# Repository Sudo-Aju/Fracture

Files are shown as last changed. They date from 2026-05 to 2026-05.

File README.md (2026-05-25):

<div align="center">

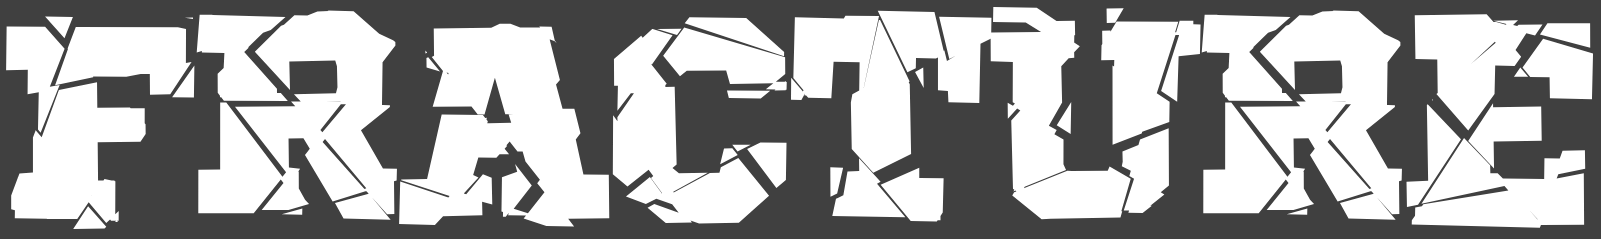
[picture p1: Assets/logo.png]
FractureLogo
# 

A Bluetooth Powered 48-Key Split Keyboard

<p>




</p>

### _A keyboard designed to physically split apart - because productivity and aesthetics shouldn't stay connected._

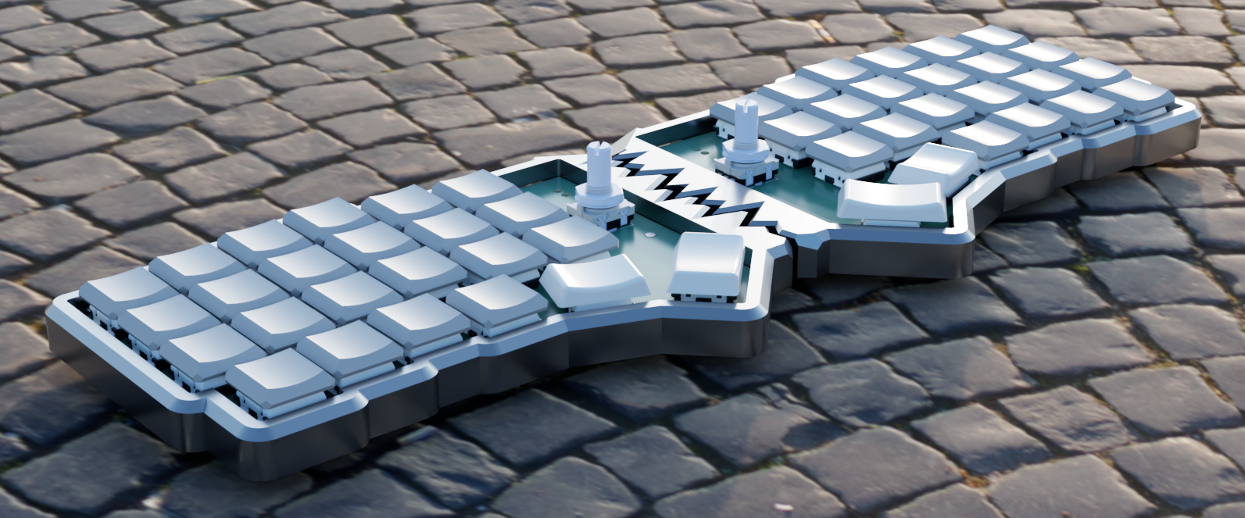
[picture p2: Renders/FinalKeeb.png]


</div>

---

# Overview

**Fracture** is a wireless 48-key split mechanical keyboard built around modularity, portability, and aesthetics.

Unlike traditional keyboards, Fracture is designed to **literally seperate into two halves**, giving users a more ergonomic typing expereience while creating a visually unique "fractured" appearance.

Built using the **Seed Studio XIAO nRF52840**, Kailh Choc Switches, and low-profile keycaps, Fracture blends minimalism with functionaly in a compact wireless setup.

---

# Gallery

<div align="center">

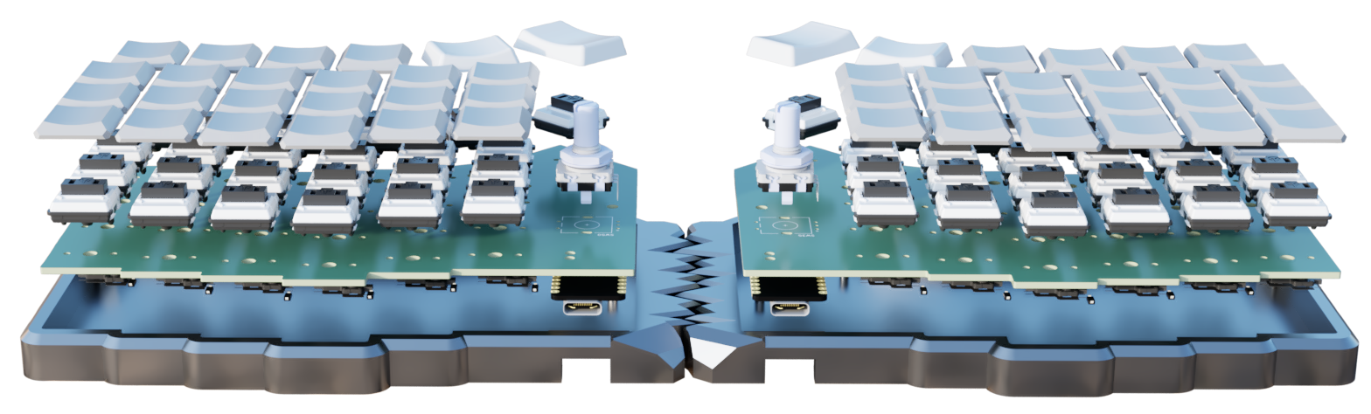
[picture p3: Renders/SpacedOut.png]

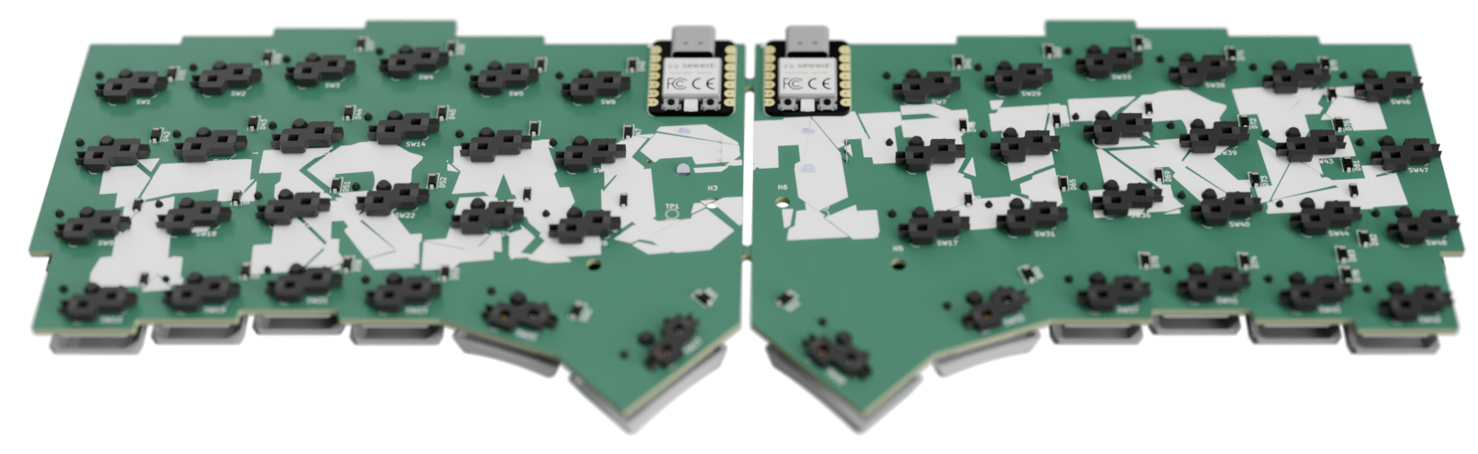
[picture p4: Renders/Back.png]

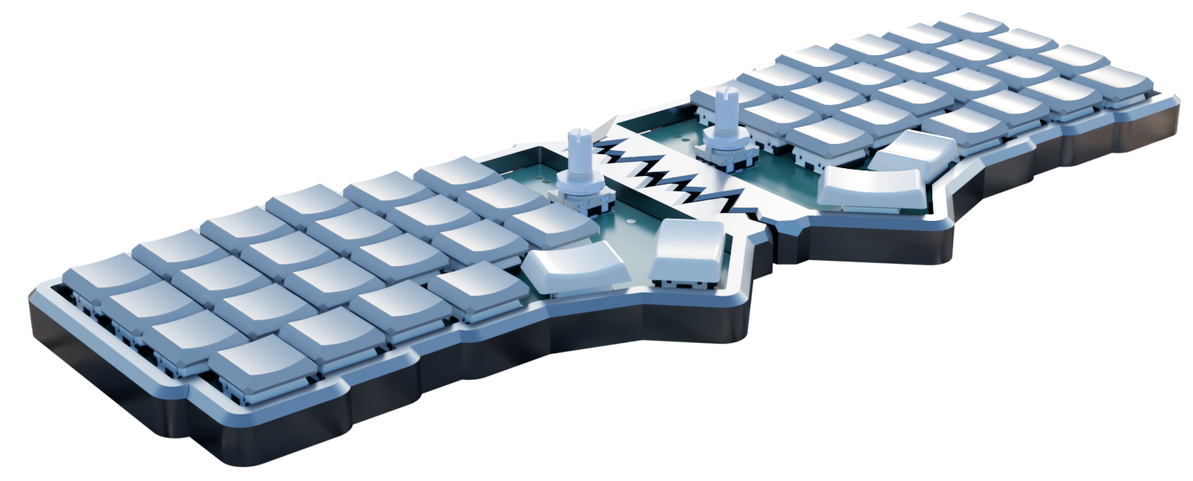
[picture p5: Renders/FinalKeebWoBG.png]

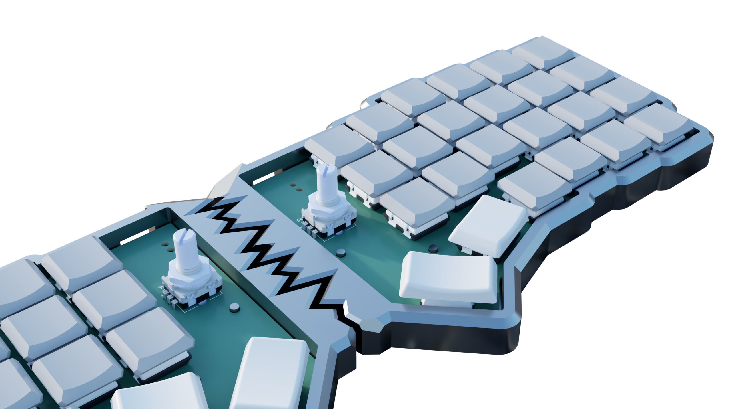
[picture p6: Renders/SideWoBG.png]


</div>

---

# Zine

<div align="center">

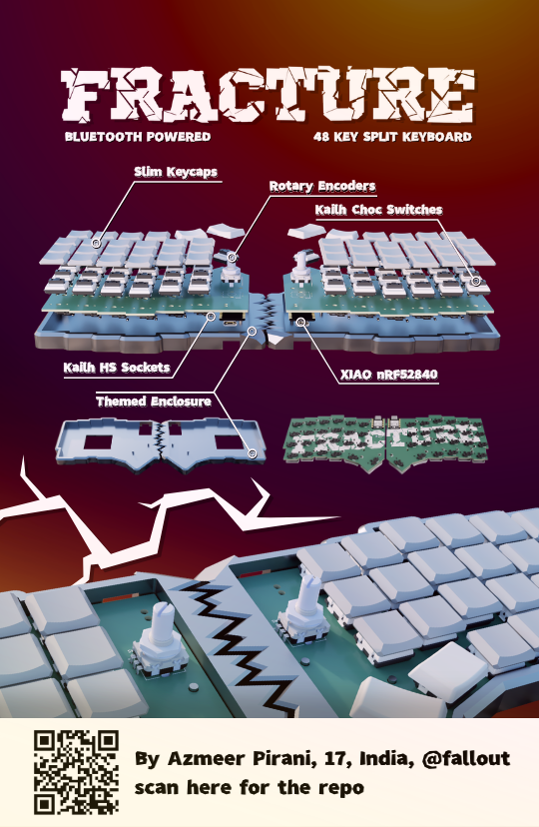
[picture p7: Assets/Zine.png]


</div>

---

# Motivation

Most keyboards are designed around a fixed layout.

Fracture was built around a different idea:

> _What if keyboard itself reflected flexibility?_

The split design is inspired from Corne keyboards:
- Better ergonomics
- Adjustable positioning
- Cleaner desk setups
- Compact portability
- A visually striking design language

The project also explores how industrial design and hardware aesthetics can coexist with practicality.

---

# Assembly Guide

## Hardware

### 1. Order the PCB

Navigate to:

```bash
PCB/Production/
```

Upload the included Gerber files to your preferred PCB manufacturer and order the PCB.

### 2. Order the Components
All required components and purchase links are available inside: (India)
```bash
PCB/BOM/BOM.csv
```
Order all listed parts before starting assembly
### 3. Solder the SMD Components

Start by soldering first few SMD components on the PCB:
- Diodes are on the front
- MCU pads are on the back

It is recommended to use:
- Flux
- Dine-tip soldering iron
- Tweezers

### 4. Install Hot-Swap Sockets
- Solder all Kailh hot-swap sockets onto the PCB carefully.

- Ensure every socket sits completely flat agains the PCB before soldering.

### 5. Install the Rotary Encoders

- Solder the EC11 rotary encoders in their designated positions.

- Make sure they are aligned staright before fully soldering.

### 6. Insert the MCU

- Now the XIAO nRF52840 (or any other if changed) controllers onto the PCB. 

### 7. Assemble the Case

- Print the 3D enclosure, and inert the PCB by aligning its M3 screw holes with the joints.

### 8. Install Switches

- Insert all Kailh Choc switches into the plate and hot-swap sockets.

- Check alignment carefully to avoid bent pins.

### 9. Install Keycaps

- Press the keycaps firmly onto the switches,

## Firmware Installation

### 1. Enter Bootloader Mode
While the keyboard is unplugged:

- Short the `BOOT` and `GND` pads using tweezers or screwdriver
- Plug in the USB cable

or

- Double press the reset button on the XIAO nRF52840

A new drive should appear on your computer

### 2. Download Firmware

Naviagte to:
```bash
Firmware/
```
and download `adafruit-circuitpython-Seeed_XIAO_nRF52840_Sense-en_US-10.2.1.uf2` or compile the files in `Firmware/Config` file if ZMK is to be used.

### 3. Flash the Firmware

Drag and drop the `uf2` file onto the mounted drive.
Repeat for the second half as well.

---

# BOM

|Designator |Function |Value |Footprint |Quantity|Price (INR)|Price (USD)|Amount |Link |
|---|---|---|---|---|---|---|---|---|
|PCB |Main PCB | | |1 |₹3,969.00  |$40.71 |$40.71 |https://www.pcbpower.com/page/PCBDetails/UXVvdGF0aW9ucw==/SU5RNjAzNTY0/ |
|Keycaps u1 1 |Slim Keycaps |Chocfox CFX Choc Blank Keycaps u1 |SW_choc_v1_HS_CPG135001S30_1u |40 |₹35.00 |$0.36 |$14.36 |https://neomacro.in/products/chocfox-cfx-choc-blank-keycaps |
|Keycaps u1 2 |Slim Keycaps |Chocfox CFX Choc Blank Keycaps u1 |SW_choc_v1_HS_CPG135001S30_1u |4 |₹35.00 |$0.36 |$1.44  |https://neomacro.in/products/chocfox-cfx-choc-blank-keycaps?variant=48049351590166 |
|Keycaps u1.25 |Slim Keycaps |Chocfox CFX Choc Blank Keycaps u1.25|SW_choc_v1_HS_CPG135001S30_1.25u |2 |₹55.00 |$0.56 |$1.13  |https://neomacro.in/products/chocfox-cfx-choc-blank-keycaps?variant=48049351622934 |
|Keycaps u1.5 |Slim Keycaps |Chocfox CFX Choc Blank Keycaps u1.5 |SW_choc_v1_HS_CPG135001S30_1.5u |2 |₹55.00 |$0.56 |$1.13  |https://neomacro.in/products/chocfox-cfx-choc-blank-keycaps?variant=48049351655702 |
|Enclosure |Print Legion | | |1 |₹400.00 |$4.10 |$4.10  |https://printlegion.hackclub.com/ |
|D35, D36, D37, D38, D39, D40, D41, D42, D43, D44, D45, D46, D47, D48, D49, D50, D51, D52, D53, D54, D55, D56, D57, D58, D59, D60, D61, D62, D63, D64, D65, D66, D67, D68, D69, D70, D71, D72, D73, D74, D75, D76, D77, D78, D80, D81, D82, D83 |Diodes |1N4148W |D_SOD-123 |48 |₹0.70 |$0.01 |$0.34  |https://robu.in/product/1n4148w-sod-123-1206-diodereel-of-3000/ |
|SW1, SW2, SW3, SW4, SW5, SW6, SW7, SW8, SW9, SW10, SW11, SW12, SW13, SW14, SW15, SW16, SW17, SW18, SW19, SW20, SW21, SW22, SW23, SW24, SW26, SW29, SW30, SW31, SW33, SW34, SW36, SW37, SW38, SW39, SW40, SW41, SW42, SW43, SW44, SW45, SW46, SW47, SW48, SW49, SW25, SW32, SW27, SW28|Keys |Kailh Choc u1 |SW_choc_v1_HS_CPG135001S30 |44 |₹54.55 |$0.56 |$24.62 |https://neomacro.in/products/kailh-choc-v1-switches |
|SW35, SW50 |Rotary Encoders |EC11 |RotaryEncoder_Alps_EC11E_Vertical_H20mm|2 |₹42.00 |$0.43 |$0.86  |https://www.flyrobo.in/ec11-rotary-encoder-half-shaft-handle-potentiometer-15mm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|
|U1, U2 |MCU |XIAO nRF52840 |modified-XIAO-nRF52840-SMD |2 |₹1,152.00  |$11.82 |$23.63 |https://robu.in/product/seeed-studio-xiao-ble-nrf52840/ |
|SW1, SW2, SW3, SW4, SW5, SW6, SW7, SW8, SW9, SW10, SW11, SW12, SW13, SW14, SW15, SW16, SW17, SW18, SW19, SW20, SW21, SW22, SW23, SW24, SW26, SW29, SW30, SW31, SW33, SW34, SW36, SW37, SW38, SW39, SW40, SW41, SW42, SW43, SW44, SW45, SW46, SW47, SW48, SW49 |Hot-swap Sockets|Kailh HS choc v1 |SW_choc_v1_HS_CPG135001S30 |48 |₹14.00 |$0.14 |$6.89  |https://neomacro.in/products/kailh-choc-pg1350-hot-swap-sockets?variant=48049369907478 |
|TOTAL | | | | | | |$119.21| |
---

# Features

- **Physically Splits Into Two Halves**
- **Bluetooth Powered**
- **48-Key Layout**
- **Rotary Encoders**
- **Low Profile Kailh Choc Switches**
- **Kailh Hot-Swap Sockets**
- **Powered by XIAO nRF52840**
- **Custom Themed Enclosure**
- **Slim Keycaps**
- **Portable & Lightweigth**
- **Fully Custom PCB**

___

# Hardware Stack

| Component | Description |
|---|---|
| MCU | Seeed Studio XIAO nRF52840 |
| Switches | Kailh Choc Low Profile |
| Sockets | Kailh Hot Swap Sockets |
| Layout | 48-key Split |
| Connectivity | Bluetooth |
| Encoders | Rotary Encoders (360 Degree Rotary Encoder EC16)
| Keycaps | Slim Low-Profile Keycaps |
| PCB | Custom Designes |
| Case | Themed Fracture Enclosure |

---

# PCB Design

The PCB was custom designed specifically for the Fracture layout and enclosure.

Features include:
- Wireless microcontroller support
- Rotary encoder integration
- Kailh hot-swap compatibility
- Compact routing for slip profile construction

## PCB
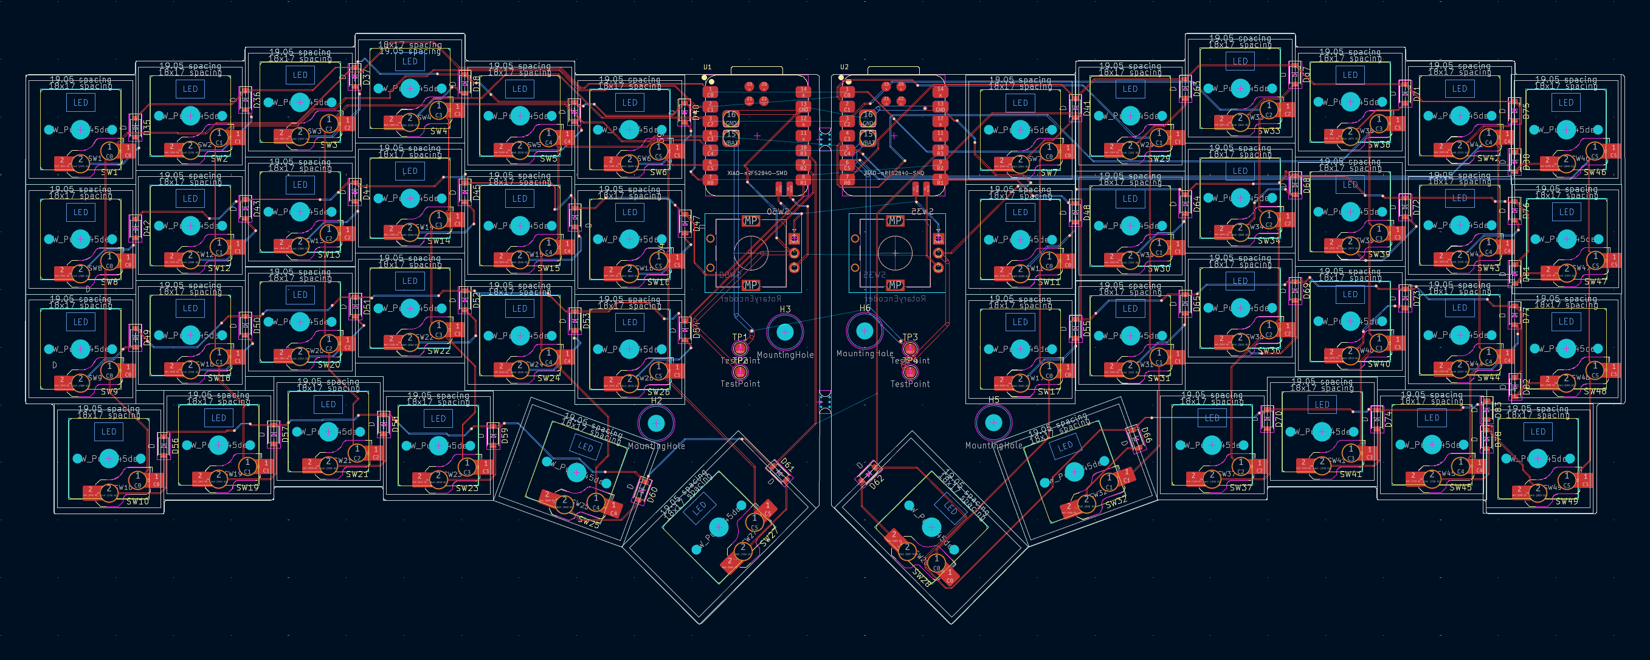
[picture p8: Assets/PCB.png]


## Schematic
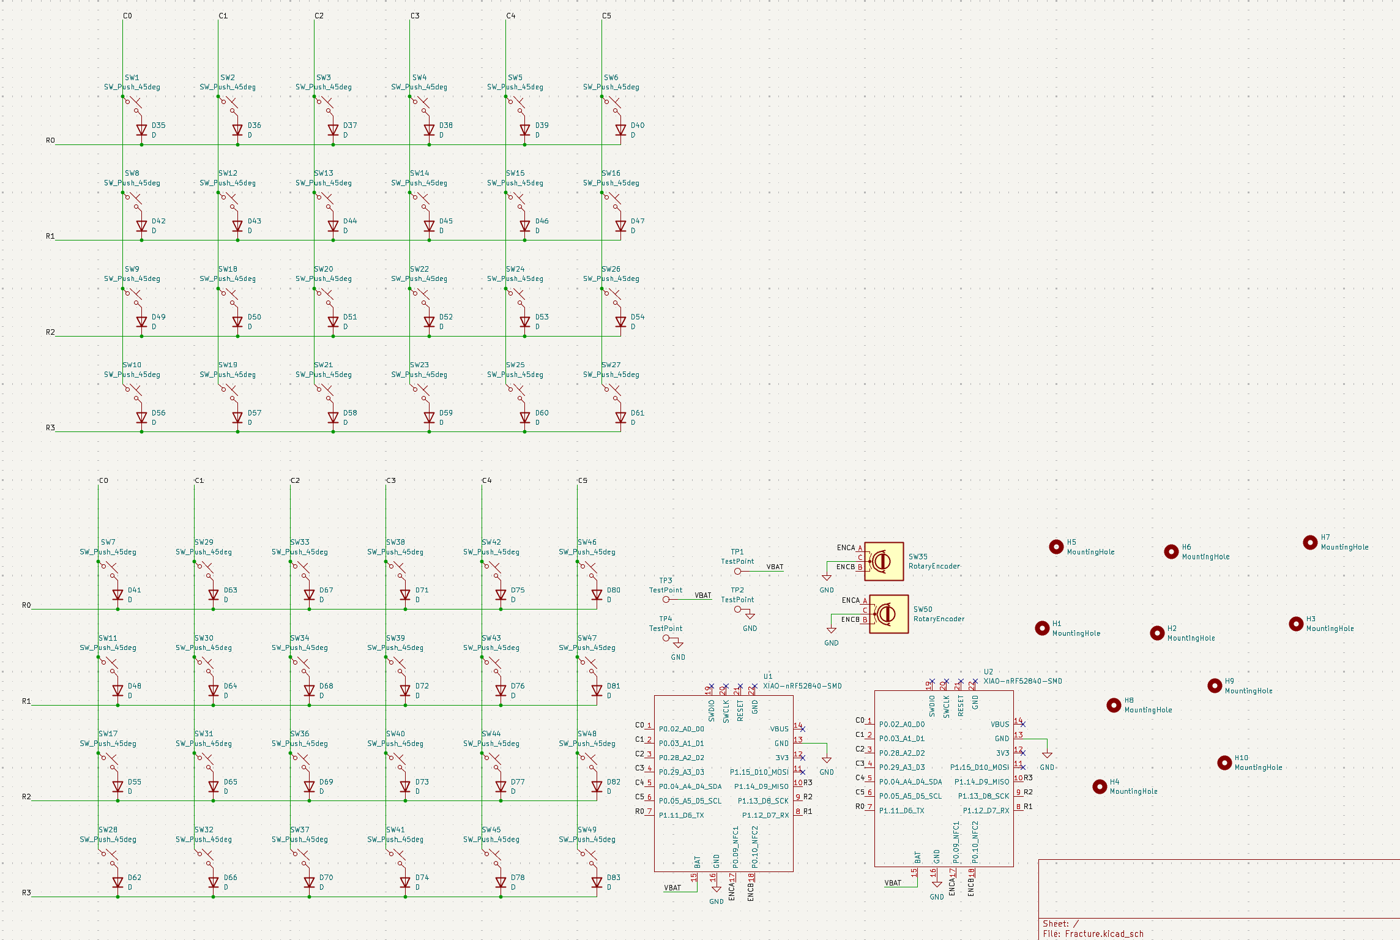
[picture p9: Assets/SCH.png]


## Placement
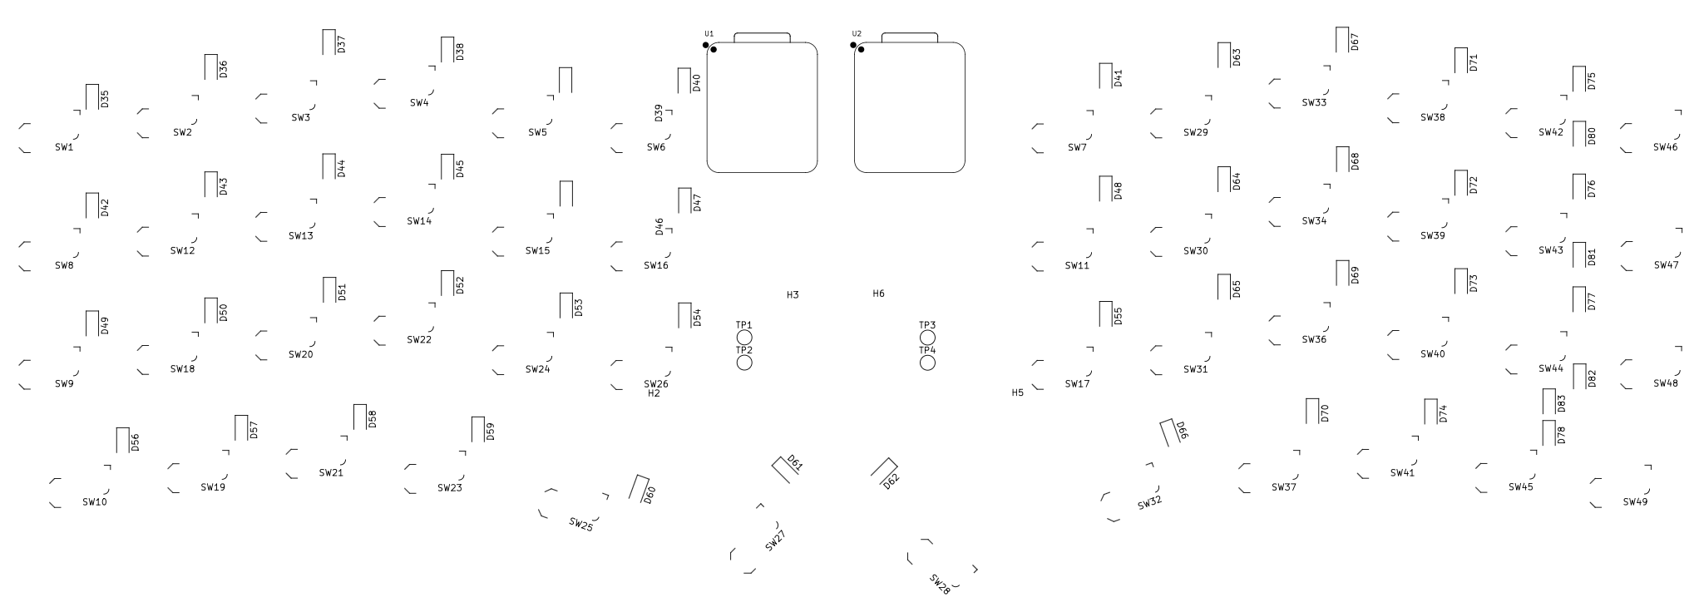
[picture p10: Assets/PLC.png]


---

# Enclosure

The enclosure follows the central "fracture" design language:
- Broken center seam
- Aggresive angular styling
- Compact low-profile body
- Seamless split mechanism

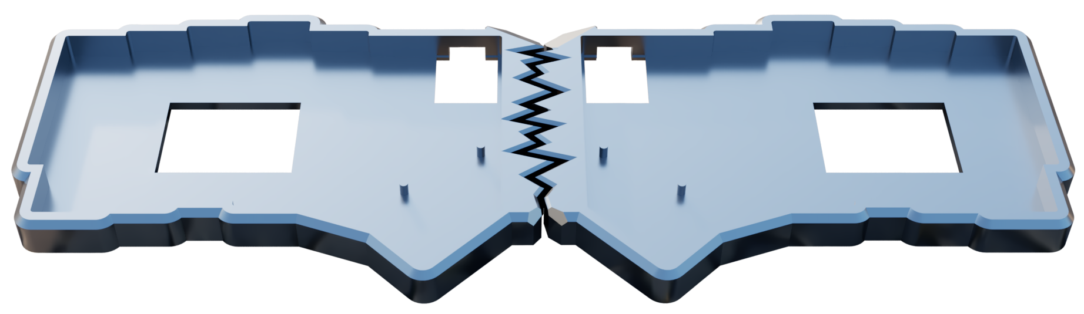
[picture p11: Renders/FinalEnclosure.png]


The goal was to make the keyboard feel more like a designed object rather than just a perpheral.

---

# Firmware (ZMK)

Firmware features:
- Bluetooth support
- Custom keymaps
- Layer switching
- Encoder controls

---

```bash
Fracture/
├── PCB/
├── CAD/
├── Firmware/
├── Assets/
└── README.md
```

---

# Current Status

- [X] Inital Concept
- [X] Layout Finalized
- [X] Enclosure Prototype
- [X] PCB design
- [X] Firmware
- [ ] Final Build
- [ ] Firmware Optimization

---

# Contributing 

Contributions, suggestions, and feedback are welcome.

If you'd like to improve Fracture:
1. Fork or Clone the repository 
```bash
git clone https://github.com/Sudo-Aju/Fracture.git
cd Fracture
```
2. Create your feature branch (if forked)
3. Commit your changes
4. Open a pull request

---

# Creator

### Azmeer Pirani
17 • India • @fallout

Built with a love for:
- hardware design
- industrial aesthetics
- mechanical keyboards
- expirimental products

---

# License

This project is licensed under the MIT License.

---

<div align="center">

## FRACTURE

### _Break the keyboard. Not the workflow._

</div>

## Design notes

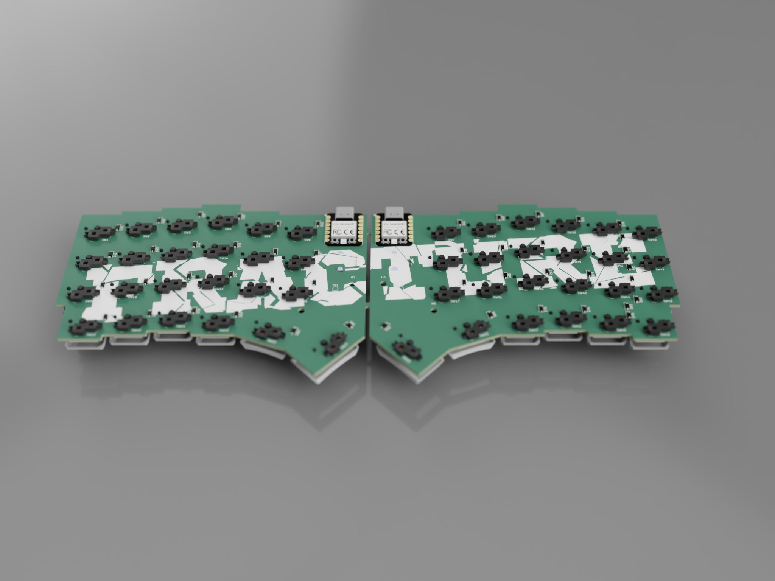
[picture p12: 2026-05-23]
Renders/render1.png

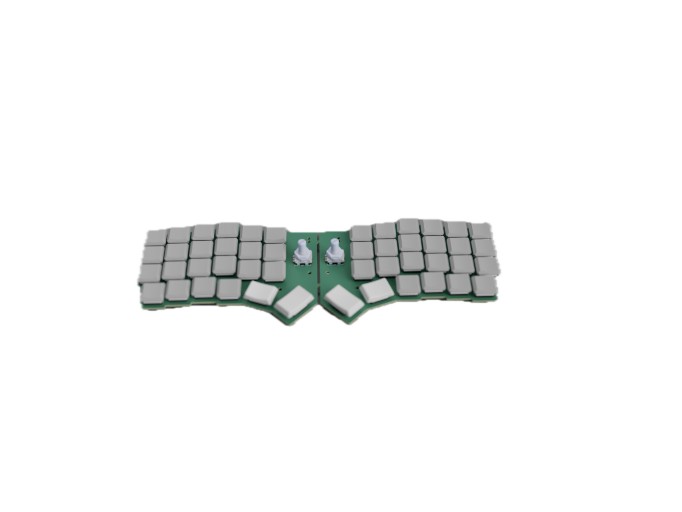
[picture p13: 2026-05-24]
Renders/render2.png

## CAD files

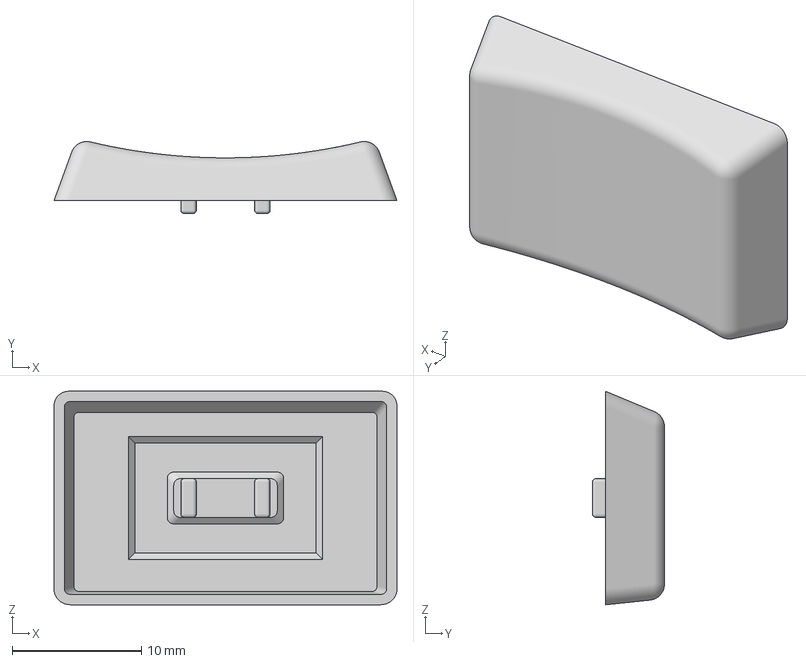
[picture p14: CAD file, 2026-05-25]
CAD/Components/Kailh Slim Keycap u1.5.3mf
26.5 x 5.56 x 16.5 mm

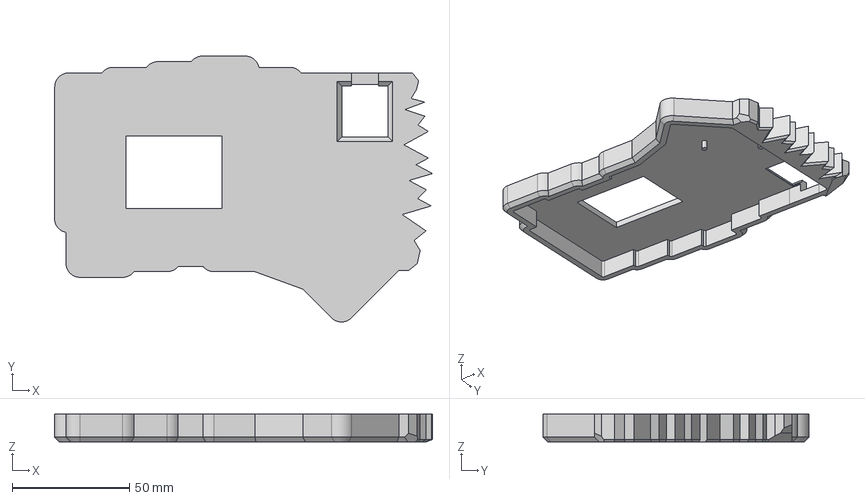
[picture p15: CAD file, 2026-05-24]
CAD/Left.step
161.4 x 113.6 x 11.8 mm

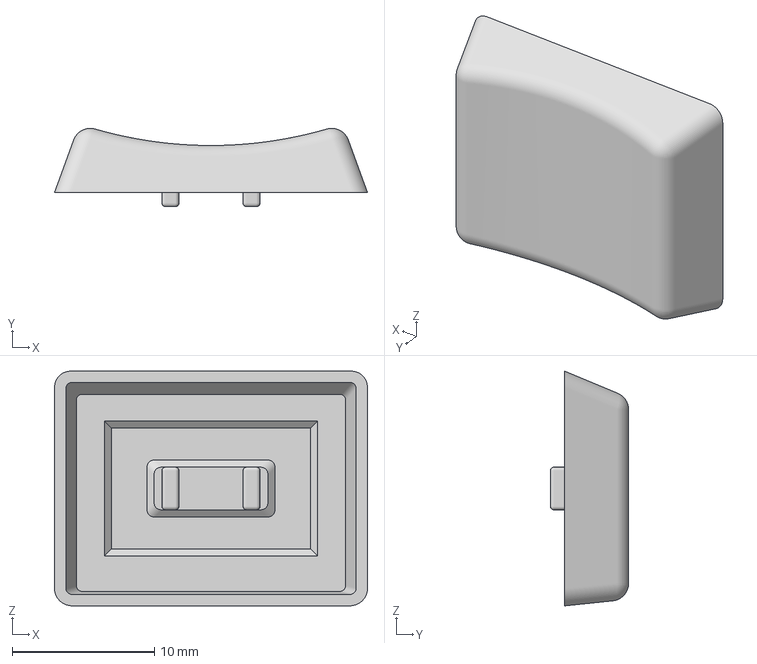
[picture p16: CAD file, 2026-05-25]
CAD/Components/Kailh Slim Keycap u1.25.3mf
22.0 x 5.50 x 16.5 mm

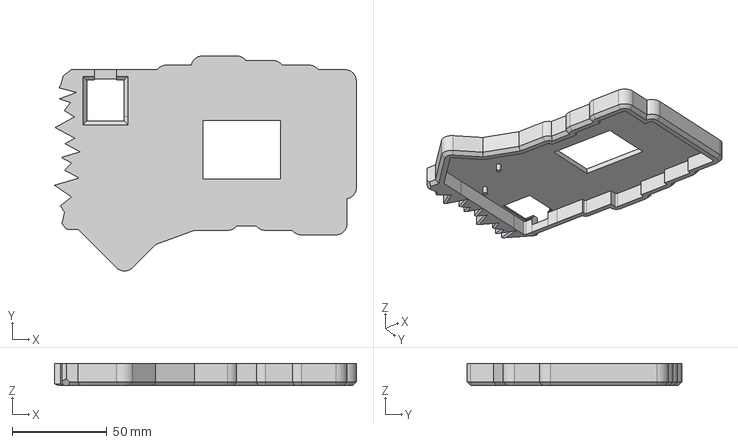
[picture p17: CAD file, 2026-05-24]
CAD/Right.step
159.5 x 113.6 x 11.8 mm

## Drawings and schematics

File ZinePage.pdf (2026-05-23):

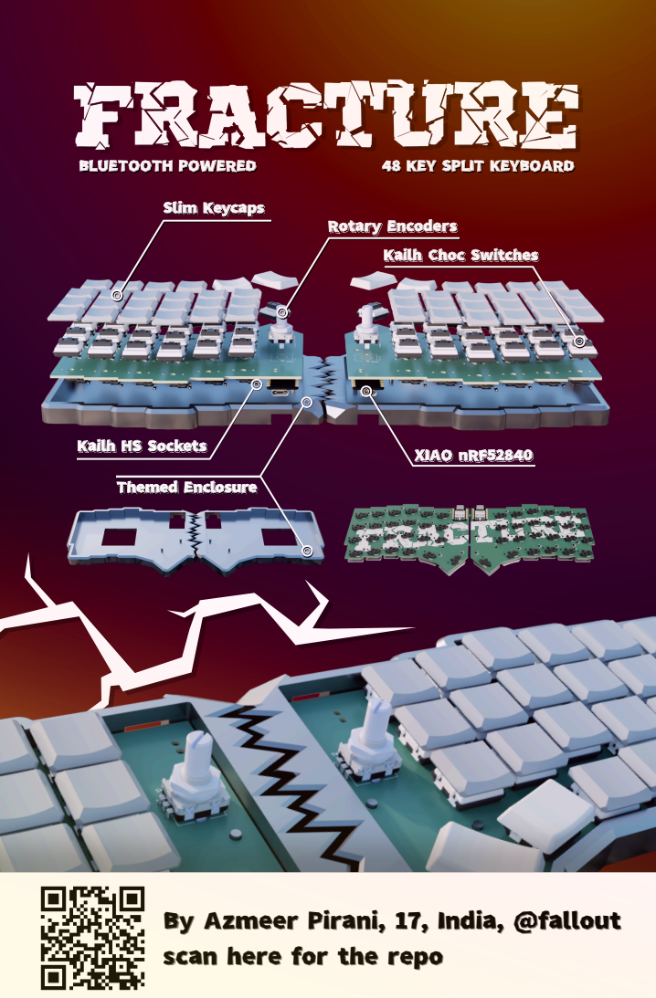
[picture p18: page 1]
SSlliimm KKeeyyccaappss; TThheemmeedd EEnncclloossuurree; XXIIAAOO nnRRFF5522884400; KKaaiillhh; HHSS SSoocckkeettss; BBBLLLUUUEEETTTOOOOOOTTTHHH PPPOOOWWWEEERRREEEDDD; 444888 KKKEEEYYY SSSPPPLLLIIITTT KKKEEEYYYBBBOOOAAARRRDDD

Rotary Encoders
Kailh Choc Switches

By Azmeer Pirani, 17, India, @fallout
scan here for the repo

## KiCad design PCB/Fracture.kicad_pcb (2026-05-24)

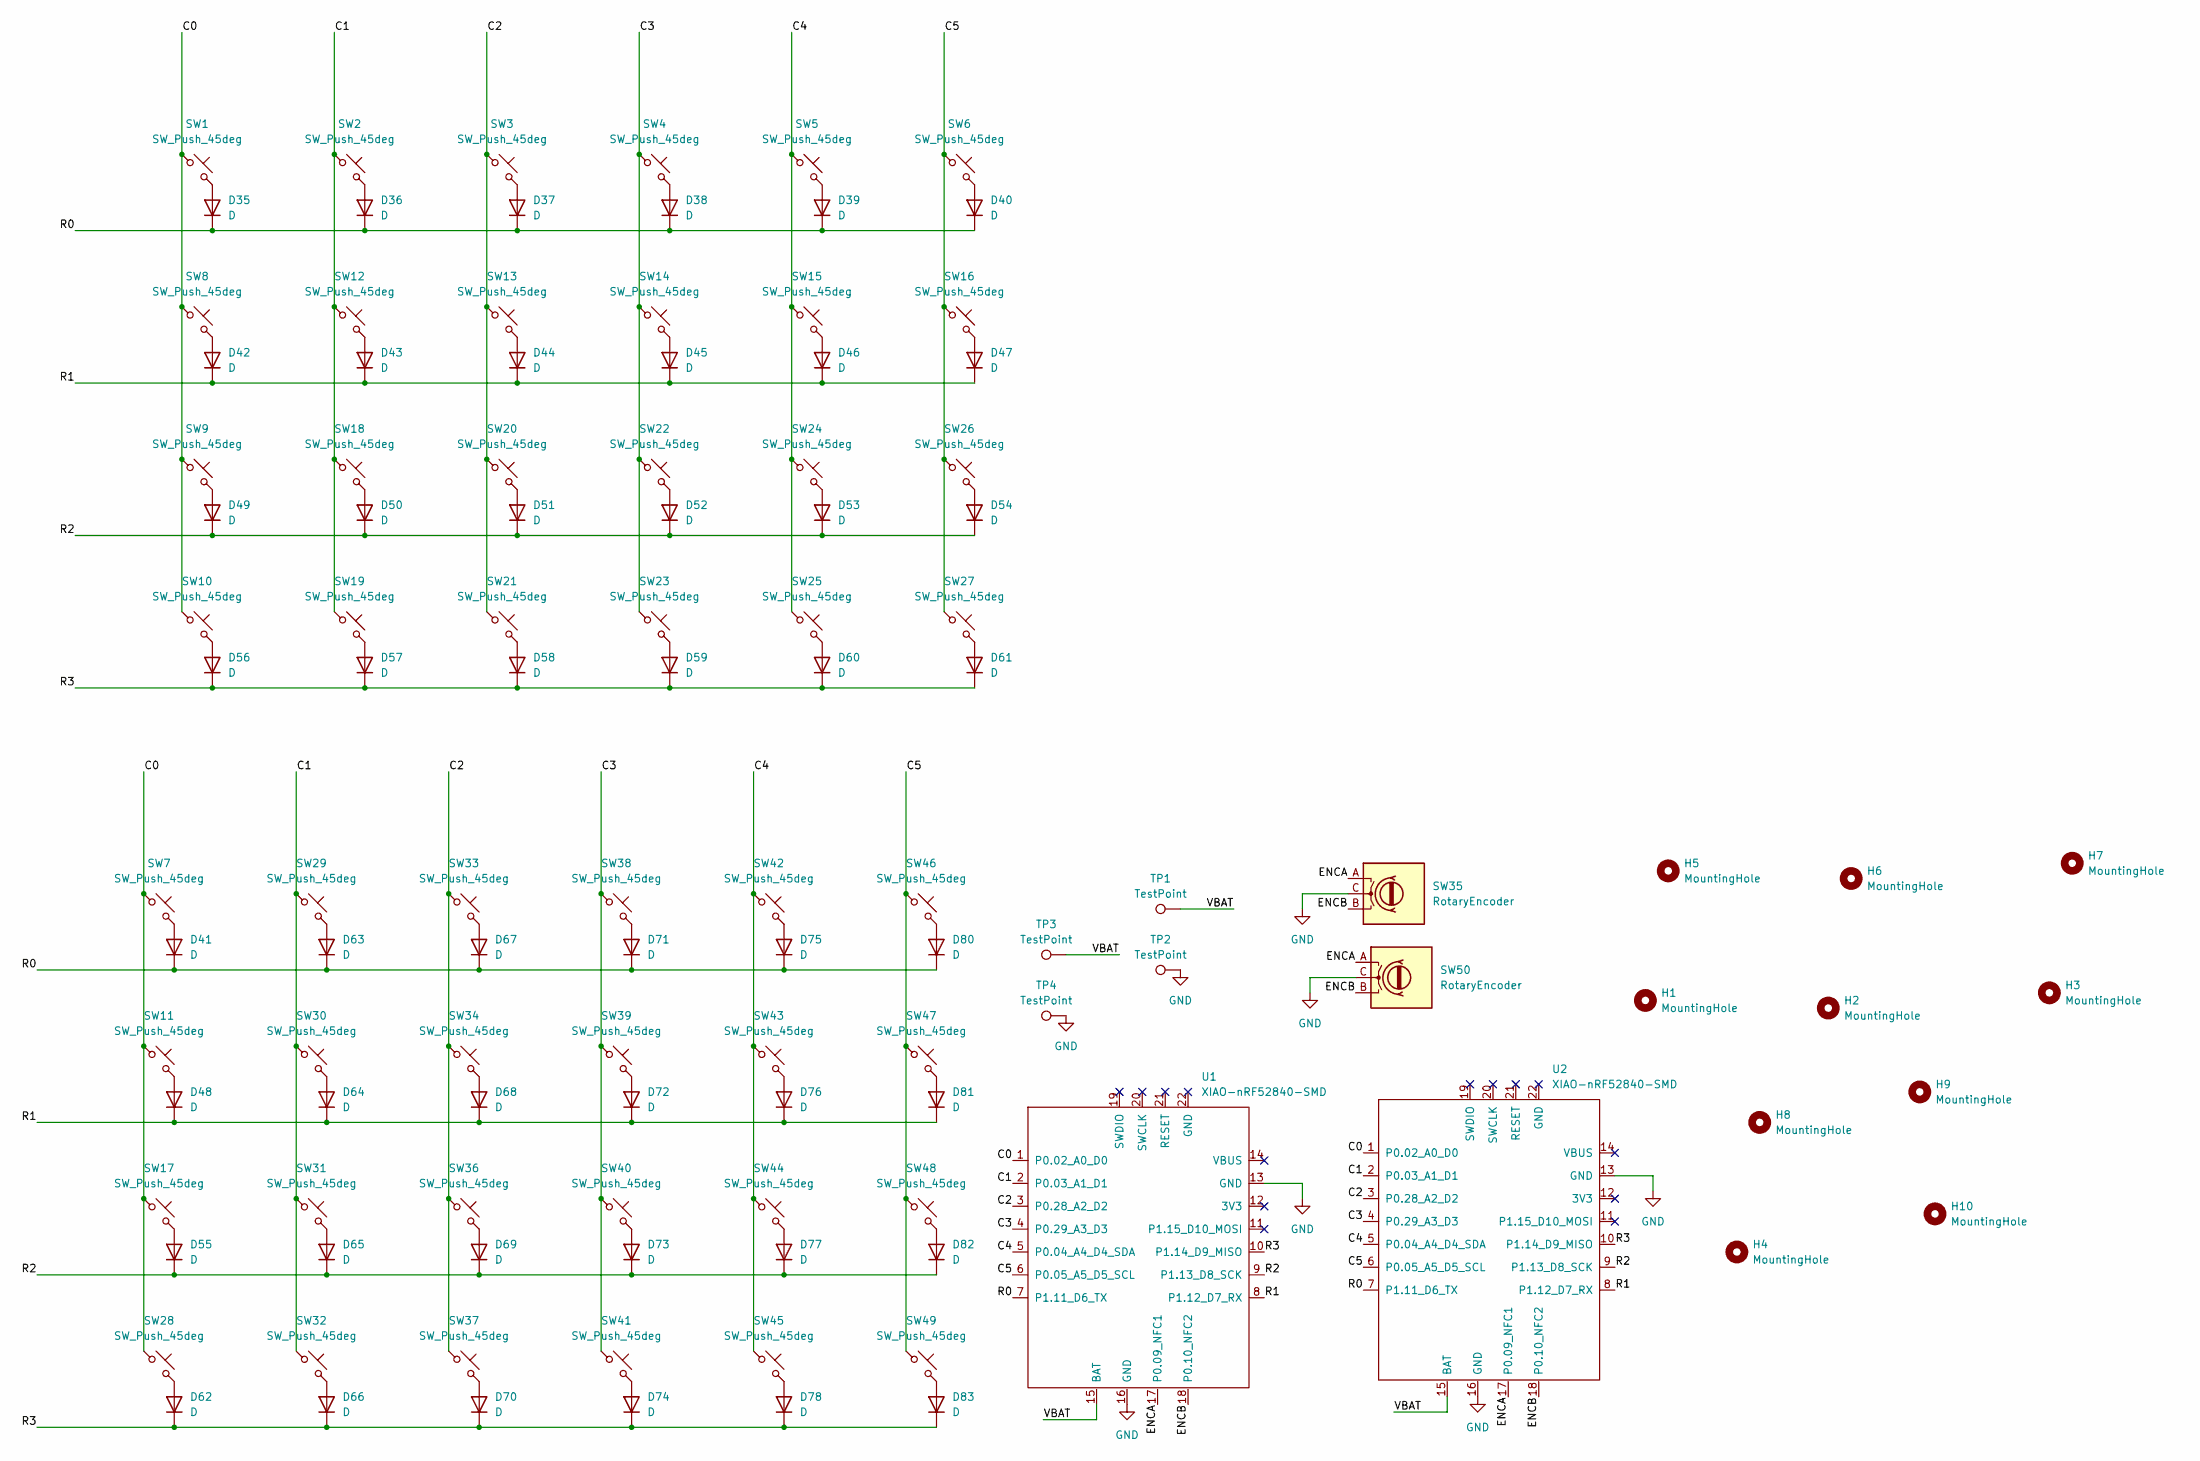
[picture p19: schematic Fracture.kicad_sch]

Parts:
D35, D36, D37, D38, D39, D40, D41, D42, D43, D44, D45, D46, D47, D48, D49, D50, D51, D52, D53, D54, D55, D56, D57, D58, D59, D60, D61, D62, D63, D64, D65, D66, D67, D68, D69, D70, D71, D72, D73, D74, D75, D76, D77, D78, D80, D81, D82, D83: D; D_SOD-123
H1, H2, H3, H4, H5, H6, H7, H8: MountingHole; MountingHole_3mm
H9, H10: MountingHole; MouseBite-Slot_2.0x2.0mm_outset_D0.5mm_P0.85mm_3h
SW1, SW2, SW3, SW4, SW5, SW6, SW7, SW8, SW9, SW10, SW11, SW12, SW13, SW14, SW15, SW16, SW17, SW18, SW19, SW20, SW21, SW22, SW23, SW24, SW25, SW26, SW27, SW28, SW29, SW30, SW31, SW32, SW33, SW34, SW36, SW37, SW38, SW39, SW40, SW41, SW42, SW43, SW44, SW45, SW46, SW47, SW48, SW49: SW_Push_45deg; SW_choc_v1_HS_CPG135001S30_1u
SW35, SW50: RotaryEncoder; RotaryEncoder_Alps_EC11E_Vertical_H20mm
TP1, TP2, TP3, TP4: TestPoint; TestPoint_Pad_D2.0mm
U1, U2: XIAO-nRF52840-SMD; modified-XIAO-nRF52840-SMD

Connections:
/C0: SW1.1, SW7.1, SW8.1, SW9.1, SW10.1, SW11.1, SW17.1, SW28.1, U1.1 (P0.02_A0_D0), U2.1 (P0.02_A0_D0)
/C1: SW2.1, SW12.1, SW18.1, SW19.1, SW29.1, SW30.1, SW31.1, SW32.1, U1.2 (P0.03_A1_D1), U2.2 (P0.03_A1_D1)
/C2: SW3.1, SW13.1, SW20.1, SW21.1, SW33.1, SW34.1, SW36.1, SW37.1, U1.3 (P0.28_A2_D2), U2.3 (P0.28_A2_D2)
/C3: SW4.1, SW14.1, SW22.1, SW23.1, SW38.1, SW39.1, SW40.1, SW41.1, U1.4 (P0.29_A3_D3), U2.4 (P0.29_A3_D3)
/C4: SW5.1, SW15.1, SW24.1, SW25.1, SW42.1, SW43.1, SW44.1, SW45.1, U1.5 (P0.04_A4_D4_SDA), U2.5 (P0.04_A4_D4_SDA)
/C5: SW6.1, SW16.1, SW26.1, SW27.1, SW46.1, SW47.1, SW48.1, SW49.1, U1.6 (P0.05_A5_D5_SCL), U2.6 (P0.05_A5_D5_SCL)
/ENCA: SW35.A, SW50.A, U1.17 (P0.09_NFC1), U2.17 (P0.09_NFC1)
/ENCB: SW35.B, SW50.B, U1.18 (P0.10_NFC2), U2.18 (P0.10_NFC2)
/R0: D35.1 (K), D36.1 (K), D37.1 (K), D38.1 (K), D39.1 (K), D40.1 (K), D41.1 (K), D63.1 (K), D67.1 (K), D71.1 (K), D75.1 (K), D80.1 (K), U1.7 (P1.11_D6_TX), U2.7 (P1.11_D6_TX)
/R1: D42.1 (K), D43.1 (K), D44.1 (K), D45.1 (K), D46.1 (K), D47.1 (K), D48.1 (K), D64.1 (K), D68.1 (K), D72.1 (K), D76.1 (K), D81.1 (K), U1.8 (P1.12_D7_RX), U2.8 (P1.12_D7_RX)
/R2: D49.1 (K), D50.1 (K), D51.1 (K), D52.1 (K), D53.1 (K), D54.1 (K), D55.1 (K), D65.1 (K), D69.1 (K), D73.1 (K), D77.1 (K), D82.1 (K), U1.9 (P1.13_D8_SCK), U2.9 (P1.13_D8_SCK)
/R3: D56.1 (K), D57.1 (K), D58.1 (K), D59.1 (K), D60.1 (K), D61.1 (K), D62.1 (K), D66.1 (K), D70.1 (K), D74.1 (K), D78.1 (K), D83.1 (K), U1.10 (P1.14_D9_MISO), U2.10 (P1.14_D9_MISO)
/VBAT: TP1.1 (1_1), TP3.1 (1_1), U1.15 (BAT), U2.15 (BAT)
GND: SW35.C, SW50.C, TP2.1 (1_1), TP4.1 (1_1), U1.13 (GND), U1.16 (GND), U2.13 (GND), U2.16 (GND)
unnamed: D35.2 (A), SW1.2
unnamed: D36.2 (A), SW2.2
unnamed: D37.2 (A), SW3.2
unnamed: D38.2 (A), SW4.2
unnamed: D39.2 (A), SW5.2
unnamed: D40.2 (A), SW6.2
unnamed: D41.2 (A), SW7.2
unnamed: D42.2 (A), SW8.2
unnamed: D43.2 (A), SW12.2
unnamed: D44.2 (A), SW13.2
unnamed: D45.2 (A), SW14.2
unnamed: D46.2 (A), SW15.2
unnamed: D47.2 (A), SW16.2
unnamed: D48.2 (A), SW11.2
unnamed: D49.2 (A), SW9.2
unnamed: D50.2 (A), SW18.2
unnamed: D51.2 (A), SW20.2
unnamed: D52.2 (A), SW22.2
unnamed: D53.2 (A), SW24.2
unnamed: D54.2 (A), SW26.2
unnamed: D55.2 (A), SW17.2
unnamed: D56.2 (A), SW10.2
unnamed: D57.2 (A), SW19.2
unnamed: D58.2 (A), SW21.2
unnamed: D59.2 (A), SW23.2
unnamed: D60.2 (A), SW25.2
unnamed: D61.2 (A), SW27.2
unnamed: D62.2 (A), SW28.2
unnamed: D63.2 (A), SW29.2
unnamed: D64.2 (A), SW30.2
unnamed: D65.2 (A), SW31.2
unnamed: D66.2 (A), SW32.2
unnamed: D67.2 (A), SW33.2
unnamed: D68.2 (A), SW34.2
unnamed: D69.2 (A), SW36.2
unnamed: D70.2 (A), SW37.2
unnamed: D71.2 (A), SW38.2
unnamed: D72.2 (A), SW39.2
unnamed: D73.2 (A), SW40.2
unnamed: D74.2 (A), SW41.2
unnamed: D75.2 (A), SW42.2
unnamed: D76.2 (A), SW43.2
unnamed: D77.2 (A), SW44.2
unnamed: D78.2 (A), SW45.2
unnamed: D80.2 (A), SW46.2
unnamed: D81.2 (A), SW47.2
unnamed: D82.2 (A), SW48.2
unnamed: D83.2 (A), SW49.2

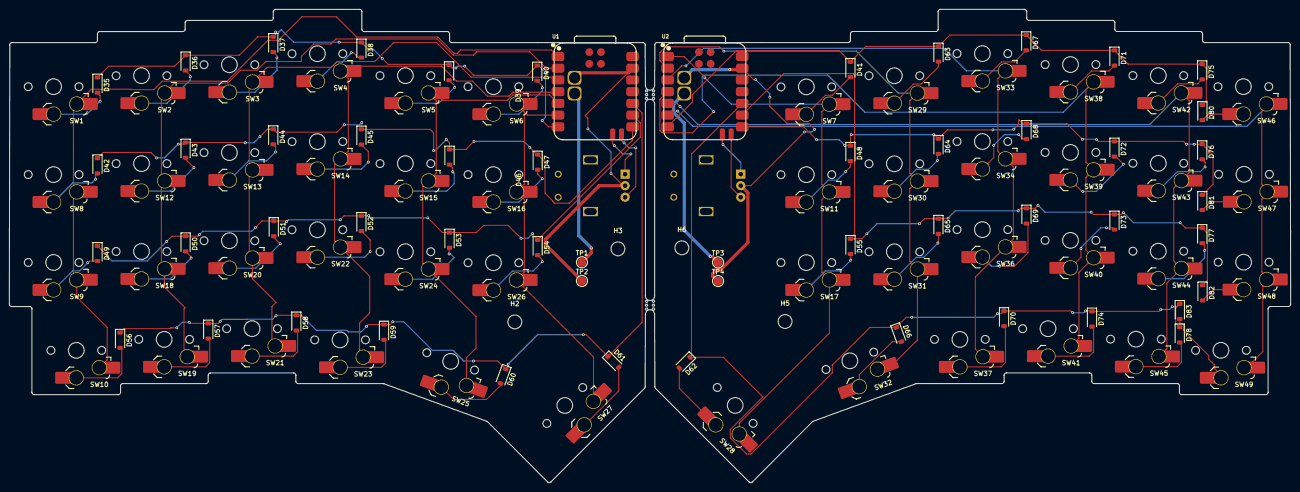
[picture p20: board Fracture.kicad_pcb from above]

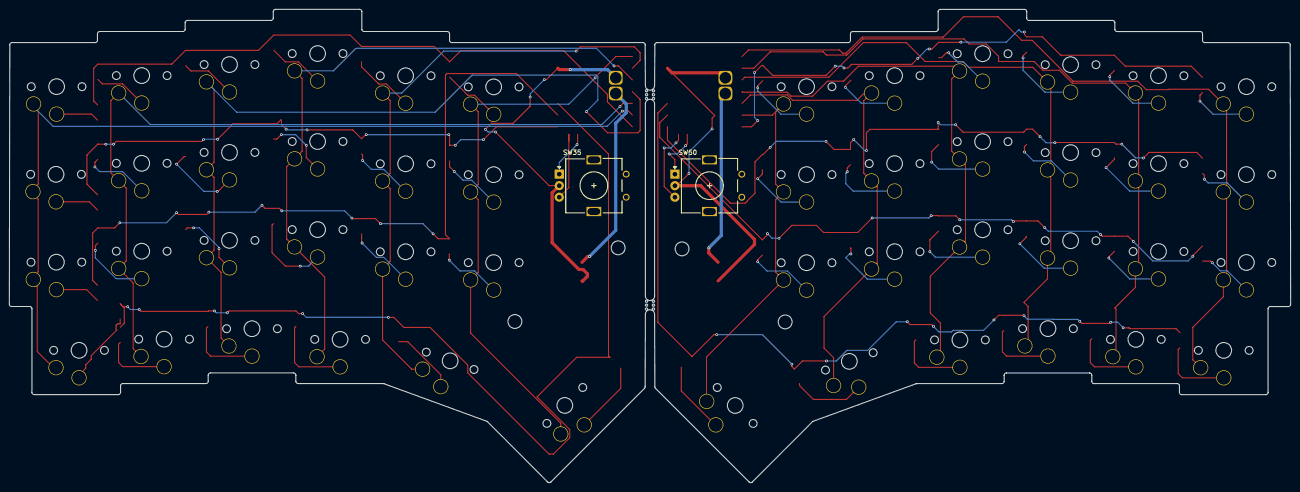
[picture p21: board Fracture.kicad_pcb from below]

Board: 2 copper layers, 277.7 x 102.6 mm, 110 parts (2 on the bottom side), 62 nets.

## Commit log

2026-05-23 first commit, i have now added all the files + the zine page
    [Enclosure.step, Enclosure.stl, Fracture.kicad_pcb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]
2026-05-24 added PCB desing and philoisy seciotn
2026-05-24 added bom
    [BOM.csv, Fracture.kicad_sch]
2026-05-24 done with the firmware
    [BOM.csv]
2026-05-24 updated the readme
    [Fracture.kicad_pcb]
2026-05-24 updated the files
    [Enclosure.step, Enclosure.stl, Left.step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]
2026-05-25 updated readme, added steps to assemble and make the keyboard
    [Positions.csv]
2026-05-25 added individual cad files for components
    [Kailh Slim Keycap u1.25.3mf, Kailh Slim Keycap u1.5.3mf]
2026-05-25 updated readme, added more instructions
    [BOM.csv]
